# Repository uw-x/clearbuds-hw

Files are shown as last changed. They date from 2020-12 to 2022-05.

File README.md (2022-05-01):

# ClearBuds: Wireless Binaural Earbuds for Learning-based Speech Enhancement

## Abstract
We present ClearBuds, the first  end-to-end hardware and software system that utilizes a neural network to enhance speech streamed from two wireless earbuds. Real-time speech enhancement for wireless earbuds  requires high-quality sound separation and background  cancellation, operating in real-time and on a mobile phone.  ClearBuds bridges state-of-the-art deep learning for blind audio source separation and in-ear mobile systems by making two key technical  contributions: 1) a new wireless earbud design capable of operating as a synchronized, binaural microphone array, and 2) a lightweight dual-channel speech enhancement neural network that runs on a mobile device. Results show that our wireless earbuds  achieve a  synchronization error less than 64 us and
our network has a runtime of 21.4 ms on an accompanying mobile phone. In-the-wild evaluation with eight users in  previously unseen indoor and outdoor multipath scenarios demonstrates that our neural network generalizes to learn both spatial and acoustic cues to  perform noise suppression and background speech removal. In a  user-study with 37 participants  who spent over 15.4  hours rating  1041   audio samples collected in-the-wild, our system achieves improved mean opinion score and background   noise  suppression.

## Contents
This directory contains the FPC (flexible printed circuit) design for ClearBuds. The FPC was designed in KiCAD 5.7.

- KiCAD design files are in shio_fpc folder.
- Fabrication output (Gerbers) are in shio_fpc/shio_rev_a_fab_v4. The suggested stack up is in shio_fpc/shio_stackup.xlsx. Suggested BOM is in shio_fpc/shio_BOM_rev_a_fab2_3.csv.
- Schematic PDF can be found at shio_fpc/shio_fpc_revA.pdf

Errata: The design contains some errors that can be addressed in future revisions. The errors do not affect function, but do affect robustness. 1. Add 0.1uF decoupling capacitor to PDM mic (ICS-41350) Vcc. 2. Extend battery holder terminal pads further under solder mask to prevent pad tearout. 3. Consider using FR4 stiffener or RFPC to better support battery holder terminal pads to prevent pad tearout.

## Hardware Setup
1. Download KiCad
-  Go to https://www.kicad.org/download/
-  Download the latest for your environment
2. Open shio_fpc/shio.pro



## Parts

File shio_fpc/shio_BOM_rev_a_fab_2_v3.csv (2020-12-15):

Component | Description | Part | References | Value | Footprint | Quantity Per PCB | Datasheet | Category | Status | Family | MPN | Digi-Key_PN | DK_Datasheet_Link | DK_Detail_Page | Manufacturer | Cost | Package | Field4 | Field6 | Field5
1 | RF ANT 2.4GHZ CHIP SOLDER SMD | 2450AT18A100E | ANT1 | 2450AT18A100E | Antenna_1.6x3.2mm_2450AT18A100E | 1 | https://www.johansontechnology.com/datasheets/2450AT18A100/2450AT18A100.pdf | RF/IF and RFID | Active | RF Antennas | 2450AT18A100E | 712-1005-1-ND | https://www.johansontechnology.com/datasheets/2450AT18A100/2450AT18A100.pdf | /product-detail/en/johanson-technology-inc/2450AT18A100E/712-1005-1-ND/1560834 | Johanson Technology Inc.
2 |  | BAT-HLD-001-THM | BT1 | BAT-HLD-001-THM | LINX_BAT-HLD-001-THM | 1 | https://linxtechnologies.com/wp/wp-content/uploads/bat-hld-001-thm.pdf |  |  |  | BAT-HLD-001-THM | BAT-HLD-001-THM-ND |  |  | Linx Technologies Inc.
3 | Unpolarized capacitor | C | C16 | 0.5pF | C_0201_0603Metric | 1 | ~ |  |  |  | 250R05L0R5BV4T | 712-1467-1-ND |  |  | Johanson Technology Inc.
4 | Unpolarized capacitor, small symbol | C_Small | C18 C19 C20 C21 | 12pF | C_0201_0603Metric | 4 | https://search.murata.co.jp/Ceramy/image/img/A01X/G101/ENG/GRM0335C1E120GA01-01.pdf |  |  |  | GRM0335C1E120GA01D | 490-11967-1-ND |  |  | Murata Electronics
5 | Unpolarized capacitor | C | C10 | 820pF | C_0201_0603Metric | 1 | ~ |  |  |  | GRM0335C1E821JA01D | 490-16368-1-ND |  |  | Murata Electronics
6 | Unpolarized capacitor | C | C2 | 47nF | C_0201_0603Metric | 1 | ~ |  |  |  | CL03A473KQ3NNNC | 1276-1336-1-ND |  |  | Samsung Electro-Mechanics
7 | Unpolarized capacitor | C | C13 C14 C15 | 100nF | C_0201_0603Metric | 3 | https://search.murata.co.jp/Ceramy/image/img/A01X/G101/ENG/GRM033C71C104KE14-01.pdf |  |  |  | GRM033C71C104KE14D | 490-10387-1-ND |  |  | Murata Electronics
8 | Unpolarized capacitor | C | C22 C23 | 100nF | C_0201_0603Metric | 2 | ~ |  |  |  |  | 490-12686-1-ND
9 | Unpolarized capacitor | C | C6 | 100nF | C_0201_0603Metric | 1 | ~ |  |  |  | CL03A104KQ3NNNC | 1276-1013-1-ND |  |  | Samsung Electro-Mechanics
10 | Unpolarized capacitor | C | C1 C12 | 1uF | C_0402_1005Metric | 2 | ~ |  |  |  | GRM155R70J105KA12J | 490-13339-1-ND |  |  | Murata Electronics
11 | Unpolarized capacitor | C | C5 C11 C17 | 1uF | C_0402_1005Metric | 3 | ~ |  |  |  | CL05A105KQ5NNNC | 1276-1010-1-ND |  |  | Samsung Electro-Mechanics
12 | Unpolarized capacitor | C | C3 C7 | 4.7uF | C_0402_1005Metric | 2 | ~ |  |  |  | CL05A475KP5NRNC | 1276-1480-1-ND |  |  | Samsung Electro-Mechanics
13 | Unpolarized capacitor | C | C8 | 4.7uF | C_0402_1005Metric | 1 | ~ |  |  |  | C1005X6S0G475M050BC | 445-8017-1-ND |  |  | TDK Corporation
14 | Unpolarized capacitor | C | C9 | 10uF | C_0402_1005Metric | 1 | ~ |  |  |  | CL05A106MP5NUNC | 1276-1450-1-ND |  |  | Samsung Electro-Mechanics
15 | Unpolarized capacitor | C | C4 | 22uF | C_0402_1005Metric | 1 | ~ |  |  |  | CL05A226MQ5N6J8 | 1276-7090-1-ND |  |  | Samsung Electro-Mechanics
16 | Light emitting diode, small symbol, filled shape | LED_Small_ALT | D1 | LED1 RED | LED_0402_1005Metric | 1 | ~ |  |  |  |  | 350-4447-1-ND
17 | Light emitting diode, small symbol, filled shape | LED_Small_ALT | D2 | LED2 ORG | LED_0402_1005Metric | 1 | ~ |  |  |  |  | 350-4448-1-ND
18 | CONN RCPT USB2.0 MICRO B SMD R/A | 10118193-0001LF | J1 | 10118193-0001LF | USB_Micro_B_Female_10118193-0001LF | 1 | http://www.amphenol-icc.com/media/wysiwyg/files/drawing/10118193.pdf | Connectors, Interconnects | Active | USB, DVI, HDMI Connectors | 10118193-0001LF | 609-4616-1-ND | http://www.amphenol-icc.com/media/wysiwyg/files/drawing/10118193.pdf | /product-detail/en/amphenol-icc-fci/10118193-0001LF/609-4616-1-ND/2785380 | Amphenol ICC (FCI)
19 | Inductor | L | L4 L6 | 0R | L_0201_0603Metric | 2 | ~ |  |  |  | RC0201JR-070RL | 311-0.0NCT-ND |  |  | Yageo
20 | Inductor | L | L5 | 2.7nH | L_0201_0603Metric | 1 | ~ |  |  |  | LQP03TN2N7BZ2D | 490-16634-1-ND |  |  | Murata Electronics
21 | Inductor | L | L8 | 3.9nH | L_0201_0603Metric | 1 | ~ |  |  |  | L-07C3N9SV6T | 712-1459-1-ND |  |  | Johanson Technology Inc.
22 | Inductor | L | L2 | 15nH | L_0201_0603Metric | 1 | https://search.murata.co.jp/Ceramy/image/img/P02/JELF243C-0015.pdf |  |  |  | LQP03TN15NJ02D | 490-5570-1-ND |  |  | Murata Electronics
23 | Inductor | L | L1 | 2.2uH | L_0603_1608Metric | 1 | https://www.we-online.com/catalog/datasheet/7447860022.pdf |  |  |  | 7447860022 | 732-7447860022CT-ND |  |  | Würth Elektronik
24 | Inductor | L | L3 | 10uH | L_0603_1608Metric | 1 | https://product.tdk.com/info/en/catalog/datasheets/inductor_commercial_decoupling_mlz1608_en.pdf |  |  |  | MLZ1608N100LT000 | 445-6755-1-ND |  |  | TDK Corporation
25 | Inductor | L | L7 | NO_STUFF | L_0201_0603Metric | 1 | ~ |  |  |  | L-07C2N7SV6T | 712-1415-1-ND |  |  | Johanson Technology Inc.
26 |  | ICS-41350 | MK1 | ICS-41350 | MIC_ICS-41350 | 1 | https://invensense.tdk.com/wp-content/uploads/2016/02/DS-000047-ICS-41350-v1.1.pdf?ref_disty=digikey |  |  |  | ICS-41350 | 1428-1064-1-ND |  |  | TDK-InvenSense | 1.30 USD
27 | Resistor, small US symbol | R_Small_US | R2 R5 R19 R20 R21 R22 R23 R25 R33 | 0R | R_0201_0603Metric | 9 | ~ |  |  |  | RC0201JR-070RL | 311-0.0NCT-ND |  |  | Yageo
28 | Resistor, small US symbol | R_Small_US | R6 R7 | 0R | R_0402_1005Metric | 2 | ~ |  |  |  | RC0402FR-070RL | 311-0.0LRCT-ND |  |  | Yageo
29 | Resistor, small US symbol | R_Small_US | R8 R9 | 220R | R_0201_0603Metric | 2 | ~ |  |  |  | RC0201JR-07220RL | 311-220NCT-ND |  |  | Yageo
30 | Resistor, small US symbol | R_Small_US | R3 | 768k | R_0201_0603Metric | 1 | ~ |  |  |  |  | P123157CT-ND
31 | Resistor, small US symbol | R_Small_US | R1 R4 | NO_STUFF | R_0201_0603Metric | 2 | ~
32 | Resistor, small US symbol | R_Small_US | R10 R11 R28 | NO_STUFF | R_0402_1005Metric | 3 | ~
33 | Resistor, small US symbol | R_Small_US | R30 | NO_STUFF | R_0402_1005Metric | 1 | ~ |  |  |  | RC0402FR-070RL | 311-0.0LRCT-ND |  |  | Yageo
34 | SWITCH TACTILE SPST-NO 0.05A 12V | B3U-1000P | S1 | B3U-1000P | Switch_Tactile_SMD_B3U-1000P | 1 | https://omronfs.omron.com/en_US/ecb/products/pdf/en-b3u.pdf | Switches | Active | Tactile Switches | B3U-1000P | SW1020CT-ND | https://omronfs.omron.com/en_US/ecb/products/pdf/en-b3u.pdf | /product-detail/en/omron-electronics-inc-emc-div/B3U-1000P/SW1020CT-ND/1534357 | Omron Electronics Inc-EMC Div
35 |  | BMA400 | U5 | BMA400 | XDCR_BMA400 | 1 | https://ae-bst.resource.bosch.com/media/_tech/media/datasheets/BST-BMA400-DS000.pdf |  |  |  | BMA400 | 828-1081-1-ND |  |  | Bosch Sensortec |  | LGA-12
36 |  | LM66100DCKT | U1 U4 | LM66100DCKT | LM66100DCKT | 2 | https://www.ti.com/lit/ds/symlink/lm66100.pdf?HQS=TI-null-null-digikeymode-df-pf-null-wwe&ts=1591950231750 |  |  |  | LM66100DCKT | 296-53540-1-ND |  |  | Texas Instruments
37 |  | MAX38640AENT+ | U2 | MAX38640AENT+ | MAX38640AENT&plus_ | 1 | https://www.mouser.com/datasheet/2/256/MAX38640A-MAX38643B-1622807.pdf |  |  |  | MAX38640AENT+
38 |  | NRF52840-CKAA-R7 | U3 | NRF52840-CKAA-R7 | BGA94N35P10X10_360X354X51N | 1 | https://www.mouser.com/datasheet/2/297/nRF52840_PS_v1.1-1623672.pdf |  |  |  | NRF52840-CKAA-R7 |  |  |  | Nordic |  | WLCSP-94 | Nordic | IPC7351B | 0.514mm
39 | 10 pA, Ultra Low Leakage and Quiescent Current, Load Switch with Reverse Blocking, High Enable, SC-70-6 | SiP32431DR3 | U8 | SiP32431DR3 | SOT-363_SC-70-6 | 1 | http://www.vishay.com.hk/docs/66597/sip32431.pdf |  |  |  | SiP32431DR3 | SIP32431DR3-T1GE3CT-ND |  |  | Vishay Siliconix
40 |  | W25N01GVZEIG_TR | U6 | W25N01GVZEIG_TR | SON127P800X600X80-9N | 1 | None |  |  |  | W25N01GVZEIG TR | W25N01GVZEIGCT-ND |  |  | Winbond Electronics |  | WSON-8
41 | Two pin crystal, small symbol | Crystal_Small | Y1 | 32.768kHz | Crystal_SMD_3215-2Pin_3.2x1.5mm | 1 | https://media.digikey.com/pdf/Data%20Sheets/NDK%20PDFs/NX3215SA-32.768K-STD-MUA-9.pdf |  |  |  | NX3215SA-32.768K-STD-MUA-9 | 644-1155-1-ND |  |  | NDK America, Inc. |  | XTAL_3215
42 | Four pin crystal, GND on pins 2 and 4, small symbol | Crystal_GND24_Small | Y3 | 32MHz | Crystal_SMD_2016-4Pin_2.0x1.6mm | 1 | https://www.jauch.com/downloadfile/5887341fd9d6d_e24753b87ed34902e36f/jxs21wa_190403_online.pdf |  |  |  | Q 32,0-JXS21-8-10/10-FU-WA-LF | 1908-1284-1-ND |  |  | Jauch Quartz
Component Groups: | 42
Component Count: | 67
Fitted Components: | 67
Number of PCBs: | 1
Total components: | 67
Schematic Version: | A, Fab: 2
Schematic Date: | 2020-12-14
PCB Variant: | [u'default']
BoM Date: | Monday, December 14, 2020 at 09:56:30 PM
Schematic Source: | shio.sch
KiCad Version: | Eeschema (5.1.5-0-10_14)

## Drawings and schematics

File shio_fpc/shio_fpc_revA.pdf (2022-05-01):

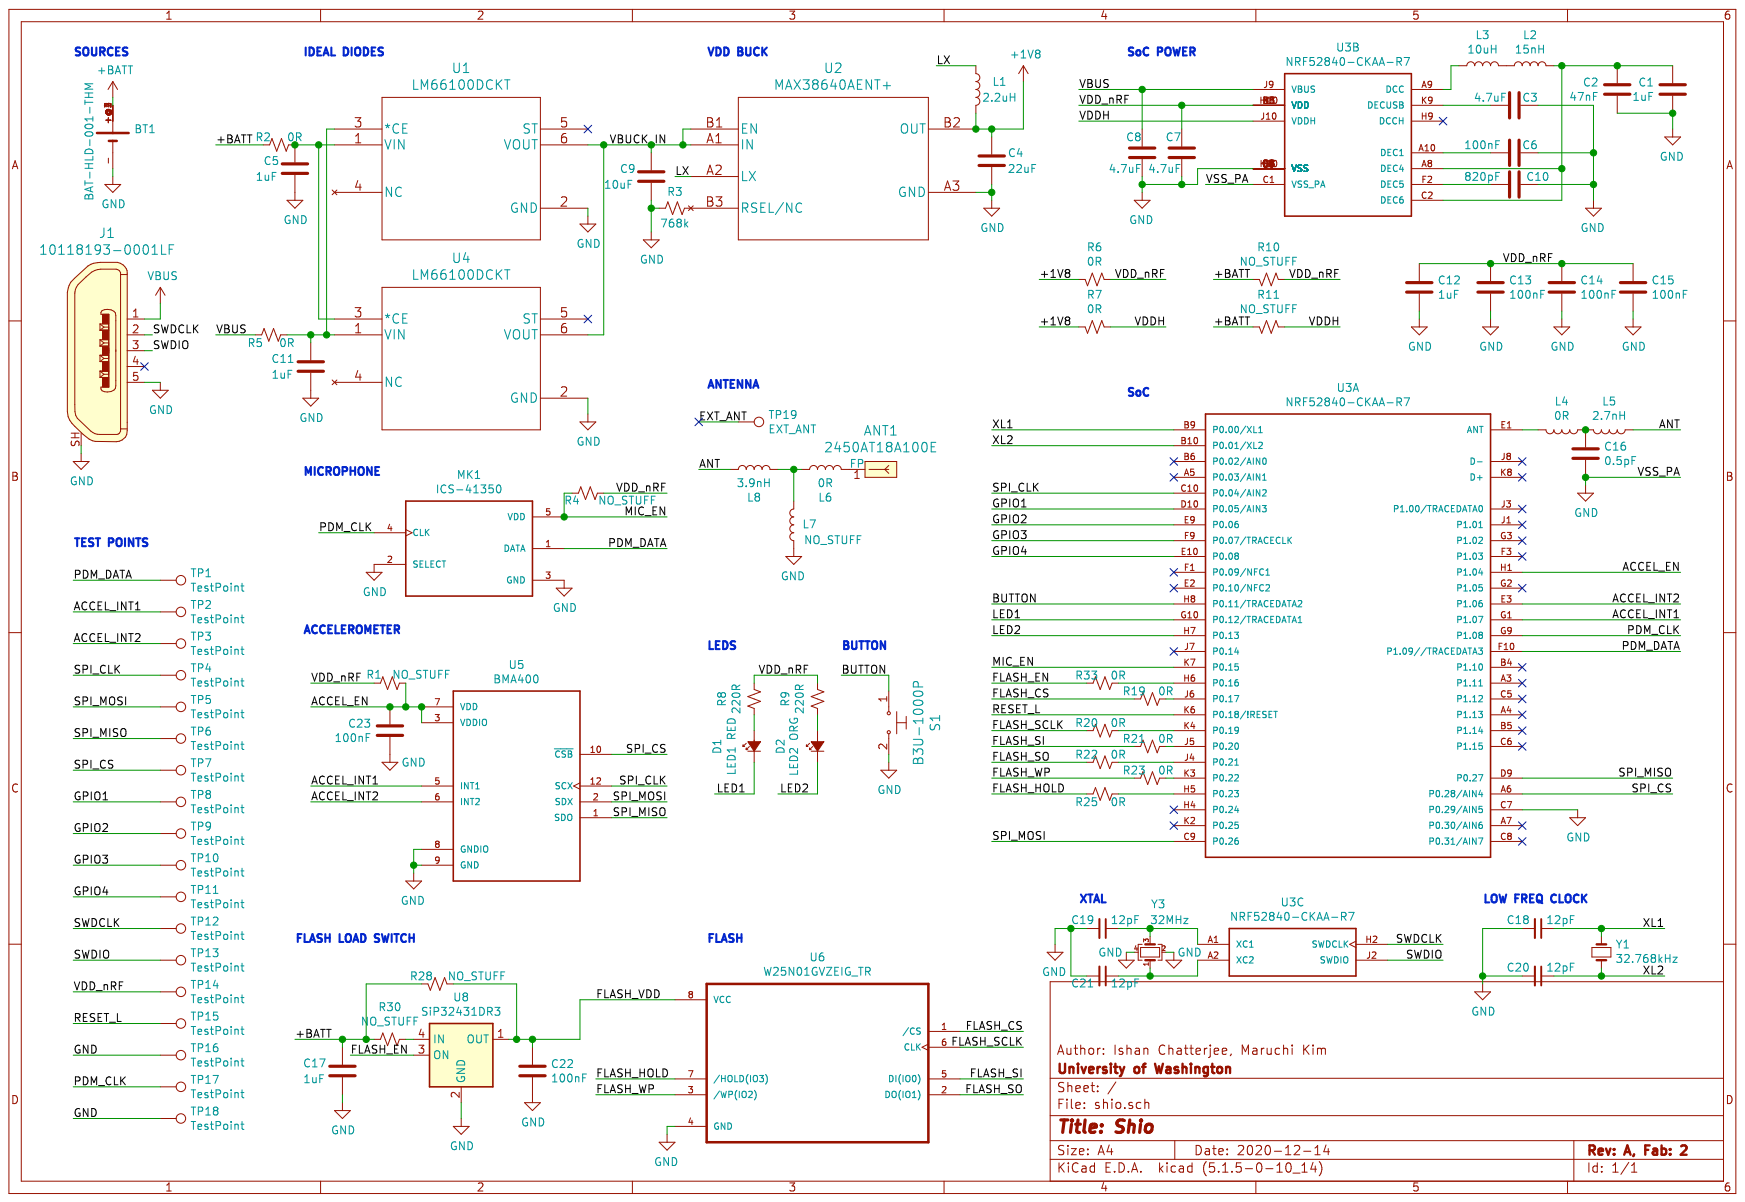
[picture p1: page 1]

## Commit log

2020-05-29 Few additions
    - Added USB micro
    - Added 2 LEDs
    - Swapped NOR for NAND memory
    - Added test points
    [shio.sch]
2020-06-01 swap out part for the BGA symbol
    [shio.sch]
2020-06-01 Add 0R resistors
    - Add option to short VBAT to VDD_nRF and bypass switches
    [shio.sch]
2020-06-02 Generated netlist
    - Matched up some symbols with their footprints
    - Need to find footprint for coin cell and micro usb
    [shio.sch]
2020-06-03 Remove project specific digikey footprints
2020-06-04 added low freq clock, style updates to schematic
    [shio.sch]
2020-06-04 Add ideal OR gates and buck converter
    [shio.sch]
2020-06-04 Add footprints
    [shio.sch]
2020-06-05 All parts have associated components
    [shio.sch]
2020-06-05 All footprints are ok in layout
    [shio.kicad_pcb, shio.sch]
2020-06-05 Add pcb bak file
2020-06-05 nRF52 reference placement done
    [shio.kicad_pcb, shio.sch]
2020-06-08 First pass at placement complete
    [shio.kicad_pcb, shio.sch]
2020-06-08 placement swag of island for layout study
    [shio.kicad_pcb]
2020-06-09 Started layout
    [shio.kicad_pcb, shio.sch]
2020-06-09 Cleaned up schematic, modified sheet
    [shio.sch]
2020-06-09 Laying out tail
    [shio.kicad_pcb]
2020-06-09 More routing
    [shio.kicad_pcb, shio.sch]
2020-06-09 Modified neck
    [shio.kicad_pcb]
2020-06-09 First pass at routing done
    [shio.kicad_pcb, shio.sch]
2020-06-10 Layout cleanup done
    [shio.kicad_pcb]
2020-06-10 added stiffeners to eco layers, modify pullback on central gnd pad
    [shio.kicad_pcb]
2020-06-10 Addressed Vikram's comments
    - spaced pdm pads by 50 mils
    - spaced swd pads by 50 mils
    - direct ground return path for antenna
    [shio.kicad_pcb]
2020-06-10 Fix silkscreen for pads that were moved
    [shio.kicad_pcb]
2020-06-10 Fix more silk screen
    [shio.kicad_pcb]
2020-06-10 Ran DRC, cleared all errors except vias under BGA which are necessary
    [shio.kicad_pcb]
2020-06-10 Move ACCEL_INT1 to pin 1.7 as 0.25 didn't work on the dev kit
    [shio.kicad_pcb, shio.sch]
2020-06-11 Added modifications to stiffener instructions on eco layers
    [shio.kicad_pcb, shio.sch]
2020-06-11 New antenna components
    - Added filter circuit for antenna
    - Added extra test point for external UFL connector compatibility
    [shio.kicad_pcb, shio.sch]
2020-06-11 Added VSS_PA ground return path
    [shio.kicad_pcb]
2020-06-12 placed and routed addtl zero ohms in case powering off gpio doesn't work, prepping for fab
    [shio.kicad_pcb, shio.sch]
2020-06-12 continue associating components with orderable parts
    [shio.sch]
2020-06-12 adding bom desc
    [shio.sch]
2020-06-12 Add more part descriptions
    - Thickened traces between between buck components
    [shio.kicad_pcb, shio.sch]
2020-06-12 Add final part descriptions
    [shio.sch]
2020-06-12 Add BOM
    [shio.csv]
2020-06-12 rename bom added gerbers added stack up
    [shio_rev_a_fab_v1_bom.csv, shio_stackup.xlsx]
2020-06-19 updated to v3 DFM release, which contain front copper and mic port hole in PI stiffener
2020-07-26 Modified component descriptions to match resistor sizes
    [shio.kicad_pcb, shio.sch]
2020-11-19 Add Udon PCB working docs, Shio BOM, sch changes
    Adding Udon PCB subfolder with supporting items
    updating the BOM of Shio PCB for 2nd build of Rev A.
    Notably, L1 max current increased, D1 changed to red for higher luminosity, LED1 and LED2 value swtiched to correspond to nets
    New BOM is exported
    Digikey PNs added in sch for most parts
    [shio-B_Cu.gbl, shio-B_Mask.gbs, shio-B_Paste.gbp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]
2020-11-21 Pushing new BOM, and BOM config
    Can now use KiBOM_CLI.py plugin with BOM.ini file to produce BOMs importable into DigiKey’s BOM manager.
    [shio.sch, shio_rev_a_fab_v2_bom.csv]
2020-12-15 Updated antenna components
    Antenna path components udpated — new BOM, sch, and PCB generated
    [shio.kicad_pcb, shio.sch, shio_BOM_rev_a_fab_2_v3.csv]
2020-12-15 Getting rid of old BOM
    [shio_rev_a_fab_v2_bom.csv]
2022-05-01 adding schematic PDF
2022-05-01 updating schematic PDF to include title block
